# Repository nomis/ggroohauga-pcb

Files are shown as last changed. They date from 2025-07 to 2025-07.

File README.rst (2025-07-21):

Logitech® Z906 Surround Sound Speakers
======================================

Overview
--------

PCBs for an alternative console and simulated amplifier interface for the
ESP32-S3 microcontroller interacting with Logitech® Z906 Surround Sound
Speakers.

    Glod picked up his horn. Cliff sat down and found his hammers. Buddy walked
    to the centre of the stage and, to Cliff's amazement, just stood there
    looking down at his feet.

    The cheering began to subside. And then it died away altogether. The huge
    hall was filled with the hush of hundreds of people holding their breath.

    Buddy's fingers moved. He picked out three simple little chords. And then he
    looked up.

    "Hello, Ankh-Morpork!"

    Cliff felt the music rise up behind him and rush him forward into a tunnel
    of fire and sparks and excitement. He brought his hammers down. And it was
    Music With Rocks In.

    -- `Terry Pratchett <https://en.wikipedia.org/wiki/Terry_Pratchett>`_
    (`Soul Music, 1994 <https://en.wikipedia.org/wiki/Soul_Music_(novel)>`_)

Purpose
-------

Provide an unofficial alternative console (to control the amplifier directly
without the original console) and simulated amplifier interface (to indirectly
control an amplifier with the original console).

Usage
-----

This project is made up of 3 KiCad projects, each of which share the same common
schematic file. These projects depend on support for symbolic links (which
can be enabled in Developer Mode if you're using Windows).

Schematic
---------

Common schematic shared by all PCBs. Components with an "A-" (amplifier)
reference are for the amplifier/bridge PCBs, components with a "C-" (console)
reference are for the console/bridge PCBs and components with an "S-" (single
DE-15 socket) reference are for the amplifier/console PCBs.

Common schematic

Amplifier PCB
~~~~~~~~~~~~~

Connect to an amplifier on its own to control the amplifier and access the Aux
Input and Headphones audio through `3.5mm TRS sockets <https://en.wikipedia.org/wiki/Phone_connector_(audio)>`_.

Dimensions: 95mm W × 31mm H

Front and back of amplifier PCB

Amplifier-specific schematic

Console PCB
~~~~~~~~~~~

Connect to a console on its own to control the console and access the Aux Input
and Headphones audio through `3.5mm TRS sockets <https://en.wikipedia.org/wiki/Phone_connector_(audio)>`_.

Dimensions: 95mm W × 31mm H

Front and back of console PCB

Console-specific schematic

Bridge PCB
~~~~~~~~~~

Connect between an amplifier and a console to control both devices
independently.

Dimensions: 98.5mm W × 31mm H

Front and back of bridge PCB

Bridge-specific schematic

Components
----------

+-------+--------------------------------------------------------+--------------------+
| Ref   | Name                                                   | PCB                |
+=======+========================================================+====================+
|       | ESP32-S3 Development Board                             | all                |
+-------+--------------------------------------------------------+--------------------+
| S3L1  | 1x20 Pin Socket, Through Hole (2.54mm)                 | all                |
+-------+--------------------------------------------------------+--------------------+
| S3R1  | 1x20 Pin Socket, Through Hole (2.54mm)                 | all                |
+-------+--------------------------------------------------------+--------------------+
| A-C1  | 0.1µF Capacitor, SMD 0805 (Metric 2012)                | amplifier, bridge  |
+-------+--------------------------------------------------------+--------------------+
| A-C2  | 0.1µF Capacitor, SMD 0805 (Metric 2012)                | amplifier, bridge  |
+-------+--------------------------------------------------------+--------------------+
| A-J1  | Amphenol L77HDE15SD1CH4R DE-15 socket                  | amplifier, bridge  |
+-------+--------------------------------------------------------+--------------------+
| A-R1  | 1kΩ Resistor, SMD 0805 (Metric 2012)                   | amplifier, bridge  |
+-------+--------------------------------------------------------+--------------------+
| A-R2  | 10kΩ Resistor, SMD 0805 (Metric 2012)                  | amplifier, bridge  |
+-------+--------------------------------------------------------+--------------------+
| A-R3  | 10kΩ Resistor, SMD 0805 (Metric 2012)                  | amplifier, bridge  |
+-------+--------------------------------------------------------+--------------------+
| A-U1  | Texas Instruments ISO6742DWR Digital Isolator, SOIC-16 | amplifier, bridge  |
+-------+--------------------------------------------------------+--------------------+
| C-J1  | Amphenol L717HDE15PD1CH4F DE-15 plug                   | console, bridge    |
+-------+--------------------------------------------------------+--------------------+
| C-Q1  | Diodes DMP2004K P-Channel MOSFET, SOT-23-3             | console, bridge    |
+-------+--------------------------------------------------------+--------------------+
| S-J1  | Same Sky SJ1-3523N 3.5mm Audio Jack                    | amplifier, console |
+-------+--------------------------------------------------------+--------------------+
| S-J2  | Same Sky SJ1-3523N 3.5mm Audio Jack                    | amplifier, console |
+-------+--------------------------------------------------------+--------------------+

Supported ESP32-S3 Boards
-------------------------

* WEMOS LOLIN S3
* Espressif ESP32-S3-DevKitC-1
* Espressif ESP32-S3-DevKitM-1

Amplifier Signals GPIOs
~~~~~~~~~~~~~~~~~~~~~~~

"Amplifier Power In" should only be pulled down, to avoid back-powering the
amplifier microcontroller when mains power is off.

When "Amplifier Power In" is active, the amplifier has mains power. Enable
"Console Announce" to turn the amplifier on, and disable it turn the amplifier
off. Don't leave it on constantly because it will heat up and waste power.
Automatic standby can be implemented by
`reading the idle time <https://github.com/nomis/logitech-z906/blob/main/protocol.rst#read-idle-time>`_.

When "Amplifier Detect" is active, the amplifier is ready to communicate over
the 3.3V UART. The labels "Amplifier RX" and "Amplifier TX" are from the
perspective of the amplifier.

+------------------------+-------+---------+-----------+-----------+----------+----------+
| Name                   |  Pin  |  LOLIN  |  DevKitC  |  DevKitM  |  Socket  |  Active  |
+========================+=======+=========+===========+===========+==========+==========+
| Amplifier Power In     |   11  |    8    |     8     |    10     |   L 12   |   High   |
+------------------------+-------+---------+-----------+-----------+----------+----------+
| Console Announce       |   15  |   41    |    41     |    42     |   R  7   |   Low    |
+------------------------+-------+---------+-----------+-----------+----------+----------+
| Amplifier Detect       |    8  |   21    |    21     |    21     |   R 15   |   Low    |
+------------------------+-------+---------+-----------+-----------+----------+----------+
| Amplifier RX           |   13  |   10    |    10     |    14     |   L 16   |          |
+------------------------+-------+---------+-----------+-----------+----------+----------+
| Amplifier TX           |   12  |    9    |     9     |    13     |   L 15   |          |
+------------------------+-------+---------+-----------+-----------+----------+----------+
| 3.3V                   |       |         |           |           |   L  1   |          |
+------------------------+-------+---------+-----------+-----------+----------+----------+
| GND                    |    6  |         |           |           |   R  1   |          |
+------------------------+-------+---------+-----------+-----------+----------+----------+

Console Signals GPIOs
~~~~~~~~~~~~~~~~~~~~~

Prepare all other GPIOs and UARTs before applying console power, otherwise it
will report a communication error.

Enable "Console Power out" to power the console on, and disable it to power off
the console. Without a `firmware modification to the console <https://github.com/nomis/logitech-z906/blob/main/firmware.rst#automatic-power-on>`_,
user intervention will be required to turn the console on after it's powered.

When "Amplifier Announce" is active, the amplifier indicates that it is ready to
communicate over the 3.3V UART. The labels "Console RX" and "Console TX" are
from the perspective of the console.

+------------------------+-------+---------+-----------+-----------+----------+----------+
| Name                   |  Pin  |  LOLIN  |  DevKitC  |  DevKitM  |  Socket  |  Active  |
+========================+=======+=========+===========+===========+==========+==========+
| Console Power Out      |   11  |   40    |    40     |    41     |   R  8   |   Low    |
+------------------------+-------+---------+-----------+-----------+----------+----------+
| Console RX             |   12  |    4    |     4     |     2     |   L  4   |          |
+------------------------+-------+---------+-----------+-----------+----------+----------+
| Console TX             |   13  |    6    |     6     |     4     |   L  6   |          |
+------------------------+-------+---------+-----------+-----------+----------+----------+
| Amplifier Announce     |    8  |   13    |    47     |    26     |   R 17   |   Low    |
+------------------------+-------+---------+-----------+-----------+----------+----------+
| Console Detect         |   15  |   17    |    17     |     8     |   L 10   |   Low    |
+------------------------+-------+---------+-----------+-----------+----------+----------+
| 3.3V                   |       |         |           |           |   L  1   |          |
+------------------------+-------+---------+-----------+-----------+----------+----------+
| GND                    |    6  |         |           |           |   R  1   |          |
+------------------------+-------+---------+-----------+-----------+----------+----------+

Board ID GPIOs
~~~~~~~~~~~~~~

To identify which type of PCB the ESP32-S3 has been connected to, read the
big-endian value of these GPIOs.

+-------+---------+-----------+-----------+
|  Bit  |  LOLIN  |  DevKitC  |  DevKitM  |
+=======+=========+===========+===========+
|   2   |    7    |     7     |     5     |
+-------+---------+-----------+-----------+
|   1   |   15    |    15     |     6     |
+-------+---------+-----------+-----------+
|   0   |   16    |    16     |     7     |
+-------+---------+-----------+-----------+

+---------+-----------+
| Value   | PCB       |
+=========+===========+
| 000 (0) | Amplifier |
+---------+-----------+
| 001 (1) | Bridge    |
+---------+-----------+
| 010 (2) | Console   |
+---------+-----------+

Related Documentation
---------------------

* `Console firmware/interface/protocol <https://github.com/nomis/logitech-z906>`_

Related Software
----------------

* `Software to interact with the console/amplifier <https://github.com/nomis/ggroohauga>`_

Notices
-------

"Logitech" is a trademark of `Logitech International SA <https://www.logitech.com/>`_.

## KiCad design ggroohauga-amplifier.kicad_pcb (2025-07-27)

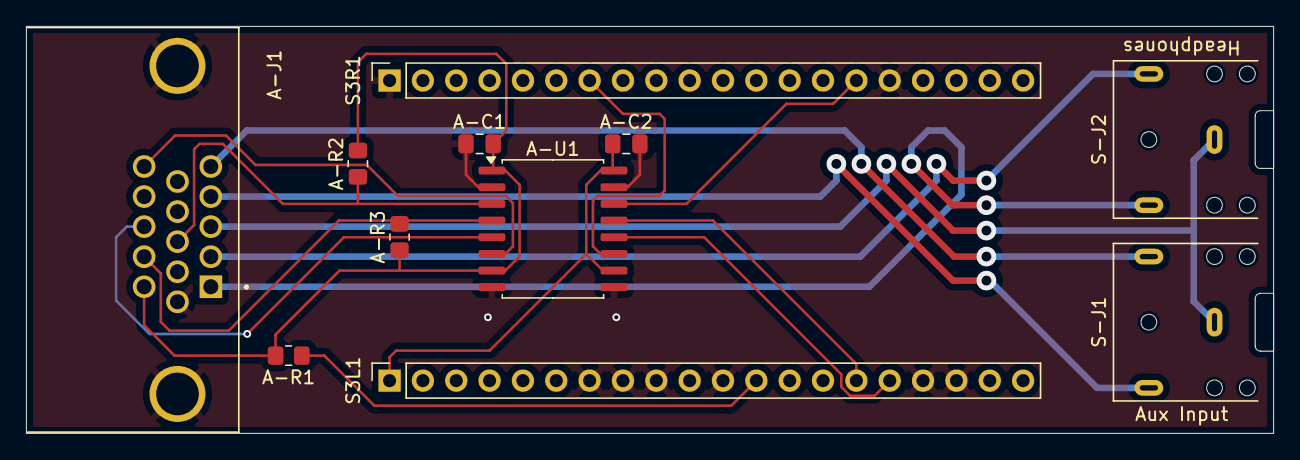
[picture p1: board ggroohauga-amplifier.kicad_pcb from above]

Board: 2 copper layers, 95.0 x 31.0 mm, 12 parts (1 on the bottom side), 17 nets.

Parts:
A-C1, A-C2: 0.1µF; C_0805_2012Metric_Pad1.18x1.45mm_HandSolder
A-J1: DE15_Socket_HighDensity_MountingHoles; AMPHENOL_L77HDE15SD1CH4R
A-R1: 1kΩ; R_0805_2012Metric_Pad1.20x1.40mm_HandSolder
A-R2, A-R3: 10kΩ; R_0805_2012Metric_Pad1.20x1.40mm_HandSolder
A-U1: ISO6742; SOIC-16W_7.5x10.3mm_P1.27mm
MUSICWITHROCKSIN: LOGO
S3L1, S3R1: Conn_01x20_Socket; PinSocket_1x20_P2.54mm_Vertical
S-J1: Aux Input; Jack_3.5mm_CUI_SJ1-3523N_Horizontal
S-J2: Headphones; Jack_3.5mm_CUI_SJ1-3523N_Horizontal

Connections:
+3.3V: A-C2.1, A-U1.10 (EN2), A-U1.16 (V_{CC2}), S3L1.1
/Common/AMP_POWER_IN: A-C1.1, A-J1.11, A-R1.2, A-R2.2, A-R3.1, A-U1.1 (V_{CC1}), A-U1.7 (EN1)
/Common/AMP_RX: A-J1.13, A-U1.5 (OUTC)
/Common/AMP_TX: A-J1.12, A-R3.2, A-U1.4 (INB)
/Common/GPIO_L8_C8_M10/AMP_POWER_IN: A-R1.1, S3L1.12
/Common/GPIO_L9_C9_M13/AMP_TX: A-U1.13 (OUTB), S3L1.15
/Common/GPIO_L10_C10_M14/AMP_RX: A-U1.12 (INC), S3L1.16
/Common/~AMP_DETECT: A-J1.8, A-R2.1, A-U1.3 (INA)
/Common/~CON_ANNOUNCE: A-J1.15, A-U1.6 (OUTD)
/Common/~GPIO_L21_C21_M21/AMP_DETECT: A-U1.14 (OUTA), S3R1.15
/Common/~GPIO_L41_C41_M42/CON_ANNOUNCE: A-U1.11 (IND), S3R1.7
AUDIO_AUX_L: A-J1.5, S-J1.T
AUDIO_AUX_R: A-J1.4, S-J1.R
AUDIO_GROUND: A-J1.3, S-J1.S, S-J2.S
AUDIO_HEADPHONES_L: A-J1.2, S-J2.T
AUDIO_HEADPHONES_R: A-J1.1, S-J2.R
GND: A-C1.2, A-C2.2, A-J1.0, A-J1.6, A-U1.2 (GND1), A-U1.8 (GND1), A-U1.9 (GND2), A-U1.15 (GND2), S3L1.7, S3L1.8, S3L1.9, S3L1.11, S3L1.17, S3L1.18, S3R1.1, S3R1.16

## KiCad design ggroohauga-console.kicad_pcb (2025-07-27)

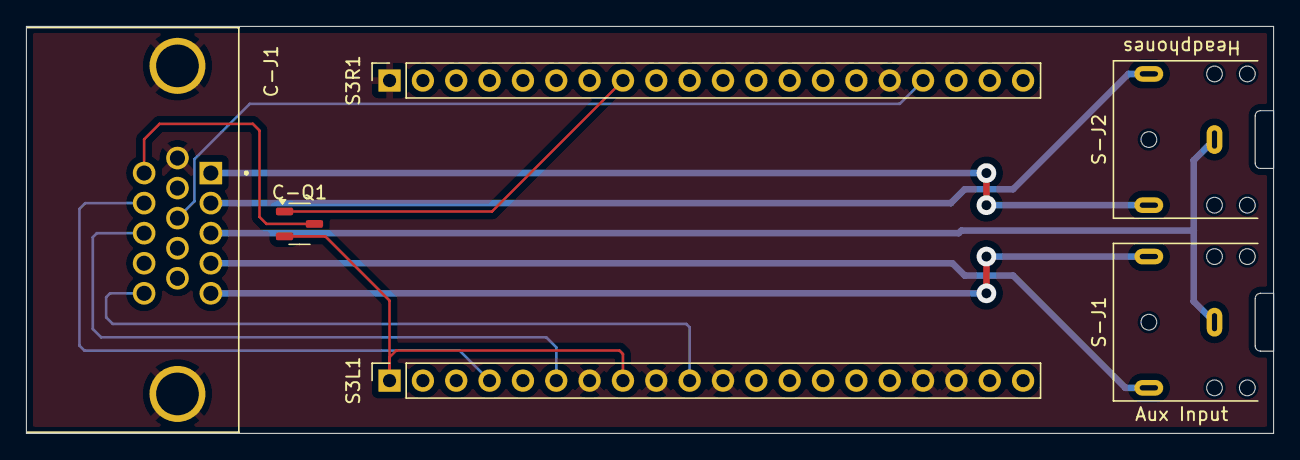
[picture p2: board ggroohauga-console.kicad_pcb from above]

Board: 2 copper layers, 95.0 x 31.0 mm, 7 parts (1 on the bottom side), 13 nets.

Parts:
C-J1: DE15_Pins_HighDensity_MountingHoles; AMPHENOL_L717HDE15PD1CH4F
C-Q1: DMP2004K; SOT-23-3
MUSICWITHROCKSIN: LOGO
S3L1, S3R1: Conn_01x20_Socket; PinSocket_1x20_P2.54mm_Vertical
S-J1: Aux Input; Jack_3.5mm_CUI_SJ1-3523N_Horizontal
S-J2: Headphones; Jack_3.5mm_CUI_SJ1-3523N_Horizontal

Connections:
+3.3V: C-Q1.2 (S), S3L1.1, S3L1.8
/Common/CON_POWER_OUT: C-J1.11, C-Q1.3 (D)
/Common/GPIO_L4_C4_M2/CON_RX: C-J1.12, S3L1.4
/Common/GPIO_L6_C6_M4/CON_TX: C-J1.13, S3L1.6
/Common/~GPIO_L13_C47_M26/AMP_ANNOUNCE: C-J1.8, S3R1.17
/Common/~GPIO_L17_C17_M8/CON_DETECT: C-J1.15, S3L1.10
/Common/~GPIO_L40_C40_M41/CON_POWER_OUT: C-Q1.1 (G), S3R1.8
AUDIO_AUX_L: C-J1.5, S-J1.T
AUDIO_AUX_R: C-J1.4, S-J1.R
AUDIO_GROUND: C-J1.3, S-J1.S, S-J2.S
AUDIO_HEADPHONES_L: C-J1.2, S-J2.T
AUDIO_HEADPHONES_R: C-J1.1, S-J2.R
GND: C-J1.0, C-J1.6, S3L1.7, S3L1.9, S3L1.11, S3L1.17, S3L1.18, S3R1.1, S3R1.16

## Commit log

2025-03-25 Create amplifier PCB
    [ggroohauga-amplifier.kicad_pcb, ggroohauga-amplifier.kicad_sch, ggroohauga-bridge.kicad_sch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]
2025-03-26 Add README file and reorganise shared files
    [ggroohauga-amplifier.kicad_pcb, ggroohauga-amplifier.kicad_sch, ggroohauga-bridge.kicad_sch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]
2025-03-26 List ESP32-S3 boards that the PCBs will support
2025-03-26 Create console PCB
    [ggroohauga-amplifier.kicad_pcb, ggroohauga-console.kicad_pcb]
2025-03-26 Create bridge PCB
    [ggroohauga-bridge.kicad_pcb]
2025-03-27 Mirror silkscreen text on the bottom
    [ggroohauga-amplifier.kicad_pcb, ggroohauga-bridge.kicad_pcb, ggroohauga-console.kicad_pcb]
2025-03-28 Align PCBs to whole mils
    [ggroohauga-amplifier.kicad_pcb, ggroohauga-bridge.kicad_pcb, ggroohauga-console.kicad_pcb]
2025-03-28 Create Gerber files
    [ggroohauga-amplifier.kicad_pcb, ggroohauga-bridge.kicad_pcb, ggroohauga-console.kicad_pcb]
2025-03-30 Fix compatibility with ESP32-S3-DevKitM-1
    [ggroohauga-amplifier.kicad_pcb, ggroohauga-bridge.kicad_pcb, ggroohauga-console.kicad_pcb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]
2025-04-08 Unhide the S3L1 silkscreen reference
    [ggroohauga-console.kicad_pcb]
2025-04-16 Connect audio pins on the bridge PCB
    [ggroohauga-bridge.kicad_pcb, ggroohauga.kicad_sch]
2025-04-17 Use thicker traces and vias for audio connections
    [ggroohauga-bridge.kicad_pcb]
2025-04-21 Fix silkscreen overlap
    [ggroohauga-bridge.kicad_pcb]
2025-04-21 Move stuff around
    [ggroohauga-bridge.kicad_pcb]
2025-04-21 Mark audio inputs/outputs differently
    [ggroohauga.kicad_sch]
2025-04-21 Rotate MOSFET pins so that it's connected correctly
    [ggroohauga-bridge.kicad_pcb, ggroohauga-console.kicad_pcb, ggroohauga.kicad_sch]
2025-04-22 Move resistor on the amplifier too
    [ggroohauga-amplifier.kicad_pcb]
2025-04-23 Fix DE-15 connector footprint so that the shield is automatically GND
    [ggroohauga-amplifier.kicad_pcb, ggroohauga-bridge.kicad_pcb, ggroohauga-console.kicad_pcb]
2025-04-23 Fix console oid
    [ggroohauga-console.kicad_pcb]
2025-04-26 Document the GPIOs for each board
2025-04-26 Document pin socket numbers
2025-04-26 Document socket positions of 3.3V and GND
2025-06-05 Cleanup tracks
    [ggroohauga-amplifier.kicad_pcb, ggroohauga-bridge.kicad_pcb, ggroohauga-console.kicad_pcb]
2025-06-08 Render the PCB as an image
2025-06-25 Fix PCB images
2025-06-25 Convert to KiCad 9.0 format
    [ggroohauga-amplifier.kicad_pcb, ggroohauga-bridge.kicad_pcb, ggroohauga-console.kicad_pcb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]
2025-06-25 Add 4ch digital isolator and 2 TRS jacks to the schematic
    [ggroohauga.kicad_sch]
2025-06-25 Add 4ch digital isolator and 2 TRS jacks to the amplifier PCB
    [ggroohauga-amplifier.kicad_pcb, ggroohauga.kicad_sch]
2025-06-25 Label other GPIOs
    [ggroohauga.kicad_sch]
2025-06-25 Reorganise schematic into multiple sheets and add 3 board identifier GPIOs
    [ggroohauga-amplifier.kicad_pcb, ggroohauga-amplifier.kicad_sch, ggroohauga-bridge.kicad_pcb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]
2025-06-25 Add 4ch digital isolator to the bridge PCB
    [ggroohauga-amplifier.kicad_pcb, ggroohauga-bridge.kicad_pcb, ggroohauga-console.kicad_pcb]
2025-06-25 Ground unused GPIOs
    [ggroohauga-amplifier.kicad_pcb, ggroohauga-bridge.kicad_pcb, ggroohauga-console.kicad_pcb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]
2025-06-25 Move bridge text out of the way of vias and cleanup tracks
    [ggroohauga-amplifier.kicad_pcb, ggroohauga-bridge.kicad_pcb]
2025-06-25 Make amplifier PCB longer to accommodate the extra 2 pins on DevKit boards
    [ggroohauga-amplifier.kicad_pcb]
2025-06-26 Add "BOARD_ID" to the GPIOs for that and fix net names on unused GPIOs
    [ggroohauga-amplifier.kicad_pcb, ggroohauga-amplifier.kicad_sch, ggroohauga-bridge.kicad_pcb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]
2025-06-27 The igital isolator should prevent back-powering on data pins
2025-06-27 Make all the PCBs a regular size, to 0.5mm
    [ggroohauga-amplifier.kicad_pcb, ggroohauga-bridge.kicad_pcb, ggroohauga-console.kicad_pcb]
2025-06-27 Add 2 TRS jacks to the console PCB
    [ggroohauga-console.kicad_pcb]
2025-06-27 Show "Headphones" and "Aux In" labels on PCBs
    [ggroohauga-amplifier.kicad_pcb, ggroohauga-console.kicad_pcb]
2025-06-27 Show extra 2 pins clearance measurements on all PCBs
    [ggroohauga-amplifier.kicad_pcb, ggroohauga-bridge.kicad_pcb, ggroohauga-console.kicad_pcb]
2025-06-27 Remove unnecessary symlink
    [ggroohauga-shared.kicad_sch, ggroohauga.kicad_sch]
2025-06-27 Add pull-up resistors to amplifier detect and RX inputs
    [ggroohauga-amplifier.kicad_pcb, ggroohauga-bridge.kicad_pcb, ggroohauga-shared.kicad_sch]
2025-06-27 Use consistent position of audio vias and rear silkscreen
    [ggroohauga-bridge.kicad_pcb]
2025-06-28 Move some stuff around on the schematic
    [ggroohauga-shared.kicad_sch]
2025-06-28 Render schematics
    [ggroohauga-amplifier.kicad_sch, ggroohauga-bridge.kicad_sch, ggroohauga-console.kicad_sch]
2025-06-28 Fix component references for audio jacks
    [ggroohauga-amplifier.kicad_pcb, ggroohauga-console.kicad_pcb, ggroohauga-shared.kicad_sch]
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2025-06-29 Add "music with rocks in" image
    [ggroohauga-amplifier.kicad_pcb, ggroohauga-bridge.kicad_pcb, ggroohauga-console.kicad_pcb]
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2025-06-29 Make bottom PCB the right way up and use the same size for all PCB images
2025-06-29 Realign amplifier and bridge PCBs so that they match
    [ggroohauga-amplifier.kicad_pcb, ggroohauga-bridge.kicad_pcb]
2025-06-29 Fix thin lines in image
    [ggroohauga-amplifier.kicad_pcb, ggroohauga-bridge.kicad_pcb, ggroohauga-console.kicad_pcb]
2025-06-29 Rename "Aux In" to "Aux Input" and document 3.5mm audio sockets
    [ggroohauga-amplifier.kicad_pcb, ggroohauga-console.kicad_pcb, ggroohauga-shared.kicad_sch]
2025-07-04 Move pull-up from AMP_RX to AMP_TX
    [ggroohauga-amplifier.kicad_pcb, ggroohauga-bridge.kicad_pcb, ggroohauga-shared.kicad_sch]
2025-07-05 Fix GPIO assignments
    Stop using GPIO 14 because the pull-up isn't working reliably on my LOLIN
    S3 board even when floating and I don't have another one to test it with.
    Don't use GPIO 35 on the DevKitC-1 board because that conflicts with the
    Octal PSRAM.
    [ggroohauga-amplifier.kicad_pcb, ggroohauga-bridge.kicad_pcb, ggroohauga-console.kicad_pcb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]
2025-07-05 Name the two different 3.3V power flags
    [ggroohauga-shared.kicad_sch]
2025-07-06 Fix edge cuts on audio connectors
    [ggroohauga-amplifier.kicad_pcb, ggroohauga-console.kicad_pcb]
2025-07-13 Fix headphones label direction
    [ggroohauga-shared.kicad_sch]
2025-07-13 Add 3D models of the DE-15 connectors and realign some tracks
    [ggroohauga-amplifier.kicad_pcb, ggroohauga-bridge.kicad_pcb, ggroohauga-console.kicad_pcb]
2025-07-20 Indicate active low signals on the schematic
    [ggroohauga-amplifier.kicad_pcb, ggroohauga-bridge.kicad_pcb, ggroohauga-console.kicad_pcb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]
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2025-07-21 Use the better SOT-23-3 footprint for C-Q1
    [ggroohauga-bridge.kicad_pcb, ggroohauga-console.kicad_pcb, ggroohauga-shared.kicad_sch]
2025-07-27 Use shorter PCB URLs
    [ggroohauga-amplifier.kicad_pcb, ggroohauga-bridge.kicad_pcb, ggroohauga-console.kicad_pcb]
